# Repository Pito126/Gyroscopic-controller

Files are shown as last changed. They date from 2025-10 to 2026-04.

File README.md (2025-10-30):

# Gyroscopic Controller

Gyroskopický ovladač postavený na mikrokontroléru **ESP32**. Tento projekt umožňuje snadné ovládání zařízení (např. her, robotů nebo dronů) pomocí pohybu ruky nebo zařízení díky vestavěnému gyroskopu a akcelerometru.

## Funkce
- **Detekce pohybu**: Real-time čtení dat z gyroskopu pro detekci rotace a akcelerace.
- **Bezdrátové připojení**: Podpora Wi-Fi a Bluetooth přes ESP32 pro snadnou integraci s aplikacemi.
- **Snadná konfigurace**: Použití Arduino IDE nebo PlatformIO pro rychlý vývoj.
- **Open-source hardware**: Kompatibilní s běžnými senzory jako MPU6050 nebo LSM6DS3 (upravte podle vašeho setupu).

## Diagramy a schémata

### Schéma zapojení (PNG)
Zde je schéma zapojení ESP32 s gyroskopickým senzorem MPU6050:

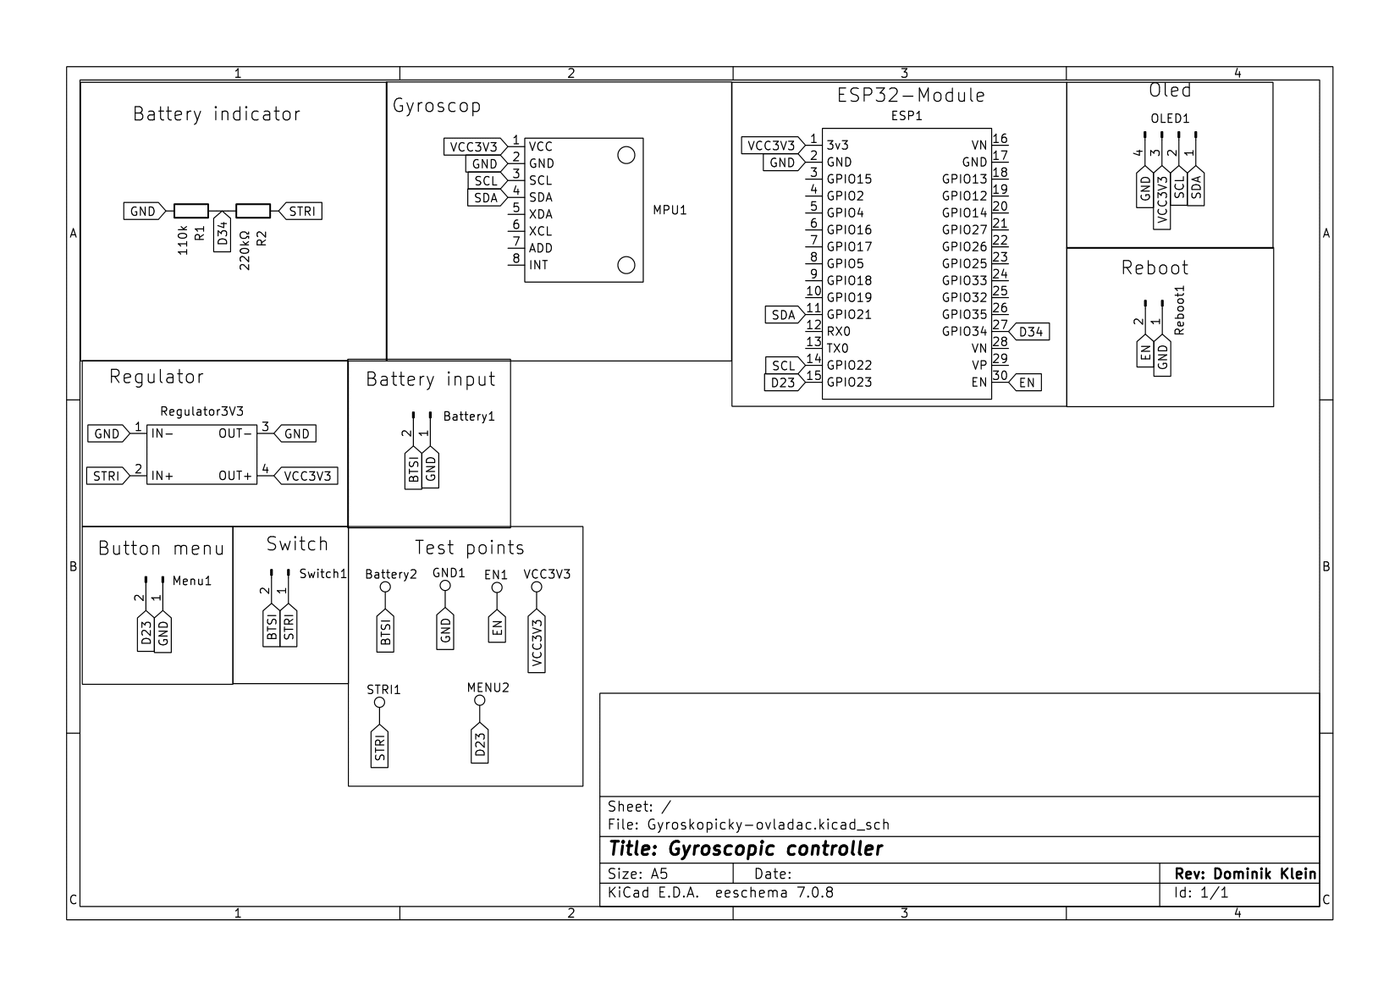
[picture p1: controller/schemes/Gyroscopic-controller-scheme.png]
Scheme


### Schéma PCB zapojení (PNG)
Zde je schéma PCB zapojení ESP32 s gyroskopickým senzorem MPU6050:

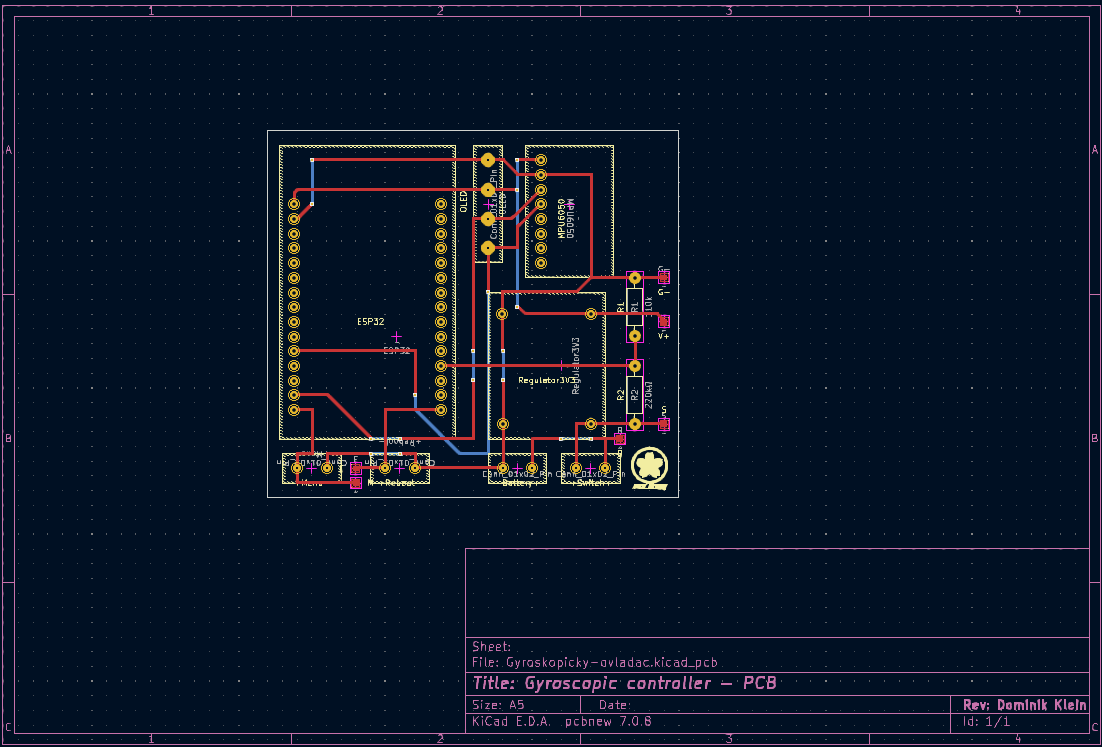
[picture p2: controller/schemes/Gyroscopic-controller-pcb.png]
Scheme-PCB)


## Požadavky
- **Hardware**:
  - ESP32 development board (např. ESP32-WROOM-32).
  - Gyroskopický senzor (např. MPU6050 připojený přes I2C).
  - Jumper wires a breadboard pro prototypování.
- **Software**:
  - Arduino IDE (verze 2.0+) s ESP32 board support.
  - Knihovny: `Wire` (pro I2C), `MPU6050` (pokud používáte tento senzor) – instalujte přes Library Manager.

## Instalace
1. Nainstalujte Arduino IDE z [oficiálního webu](https://www.arduino.cc/en/software).
2. Přidejte podporu pro ESP32: V IDE jděte do **File > Preferences**, přidejte URL `https://raw.githubusercontent.com/espressif/arduino-esp32/gh-pages/package_esp32_index.json` do Additional Board Manager URLs a nainstalujte "esp32" z Board Manager.
3. Stáhněte si tento repozitář: `git clone https://github.com/Pito126/Gyroscopic-controller.git`.
4. Otevřete soubory `.ino` v Arduino IDE.
5. Nahrajte kód na ESP32 přes USB.

## Použití
1. Připojte gyroskopický senzor k ESP32 (příklad pro MPU6050):
   - VCC → 3.3V
   - GND → GND
   - SCL → GPIO 22
   - SDA → GPIO 21
2. Nahrajte sketch (příklad v `src/main.ino` – upravte podle vašeho kódu).
3. Otevřete Serial Monitor (115200 baud) pro sledování dat pohybu.

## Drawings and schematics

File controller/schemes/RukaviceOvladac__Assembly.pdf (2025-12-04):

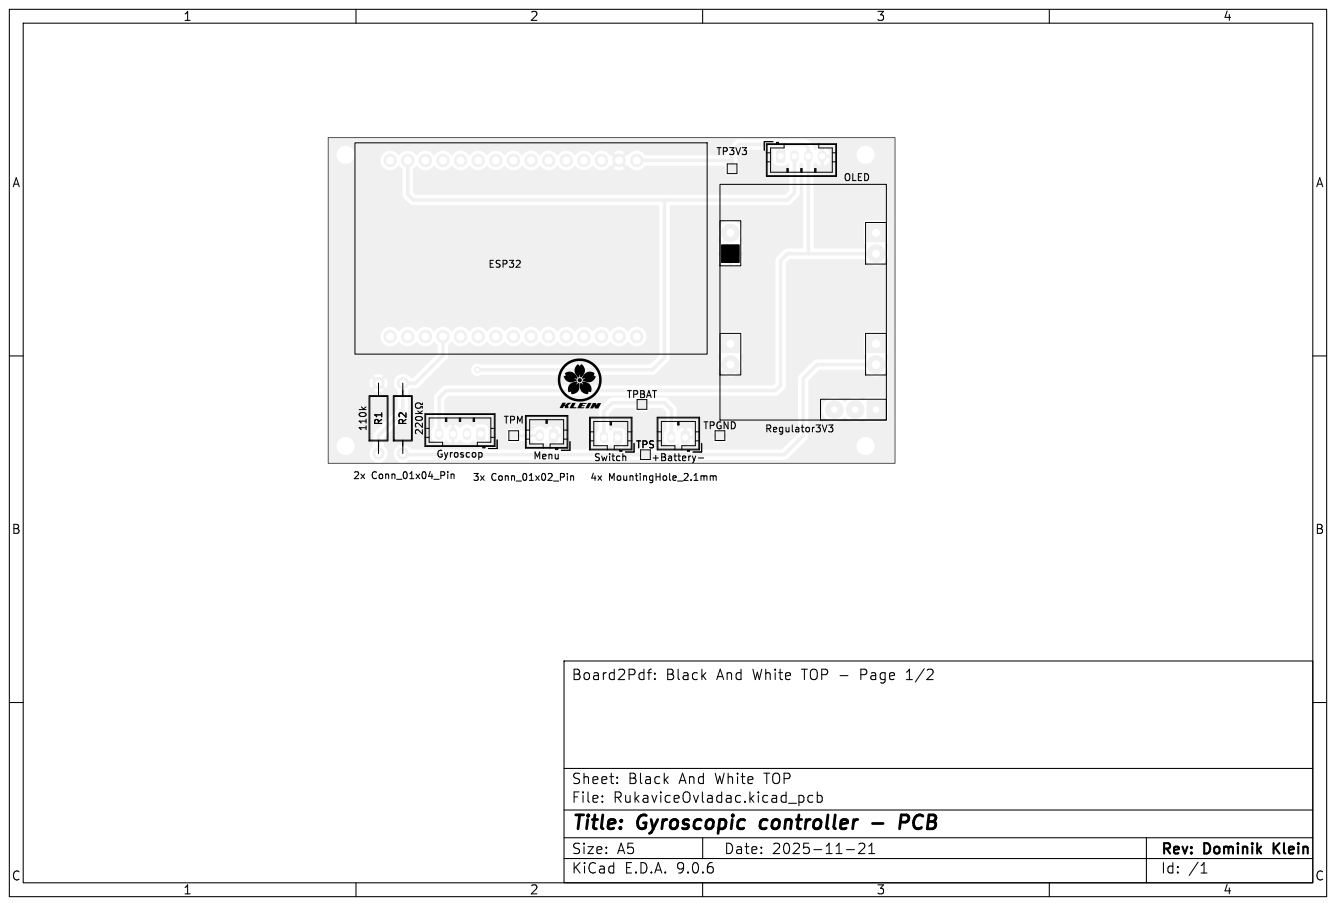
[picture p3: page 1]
+Battery-; OLED; TPS; Regulator3V3 TP3V3 TPBAT Switch ESP32; Menu; TPGND TPM; Gyroscop R¹; BC Date: 2025-11-21 KiCad; E.D.A. 9.0.6 Size: A5; Rev:; Dominik; Klein; File:; RukaviceOvladac.kicad_pcb Sheet:; Black; And; White; TOP; Board2Pdf:; And White; TOP -; Page; 4x MountingHole_2.1mm; 2x Conn_01x04_Pin; 3x Conn_01x02_Pin þÿ220k© R² 110k R¹

Id: /1 Title: Gyroscopic controller - PCB

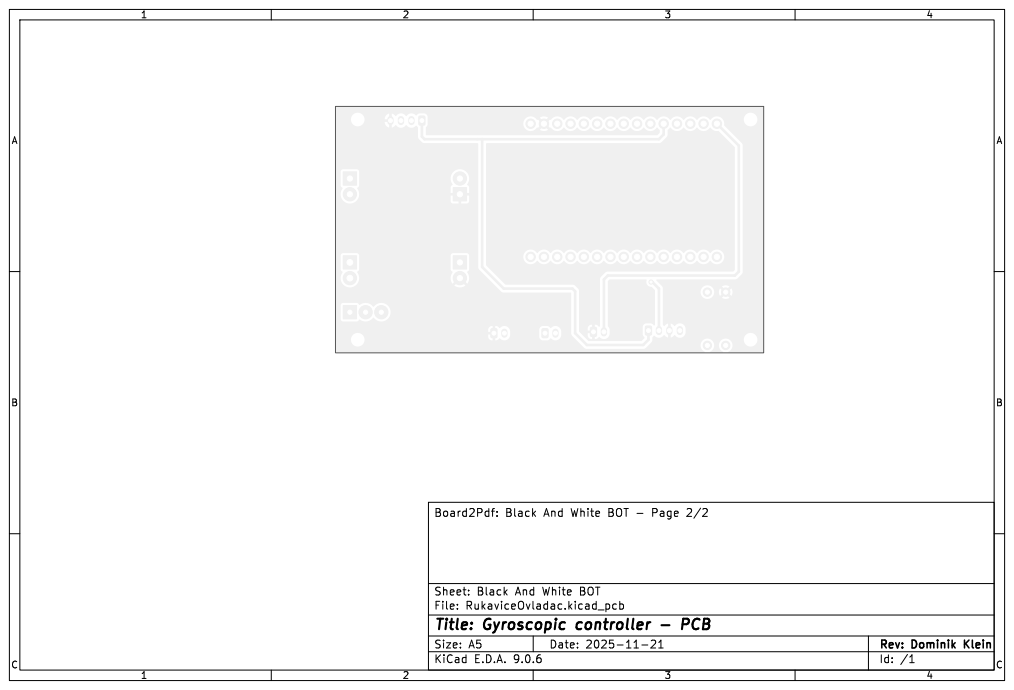
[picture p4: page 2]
BC Date: 2025-11-21 KiCad; E.D.A. 9.0.6 Size: A5; Rev:; Dominik; Klein; File:; RukaviceOvladac.kicad_pcb Sheet:; Black; And; White; BOT Board2Pdf:; And White; BOT -; Page 2/2

Id: /1 Title: Gyroscopic controller - PCB

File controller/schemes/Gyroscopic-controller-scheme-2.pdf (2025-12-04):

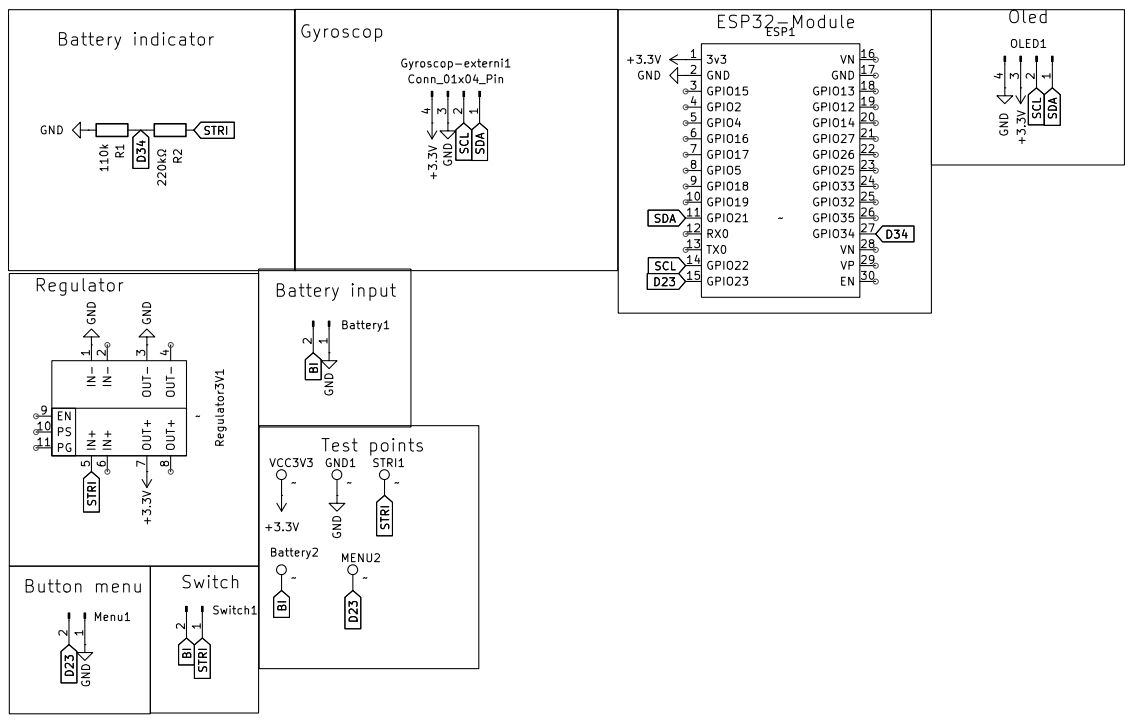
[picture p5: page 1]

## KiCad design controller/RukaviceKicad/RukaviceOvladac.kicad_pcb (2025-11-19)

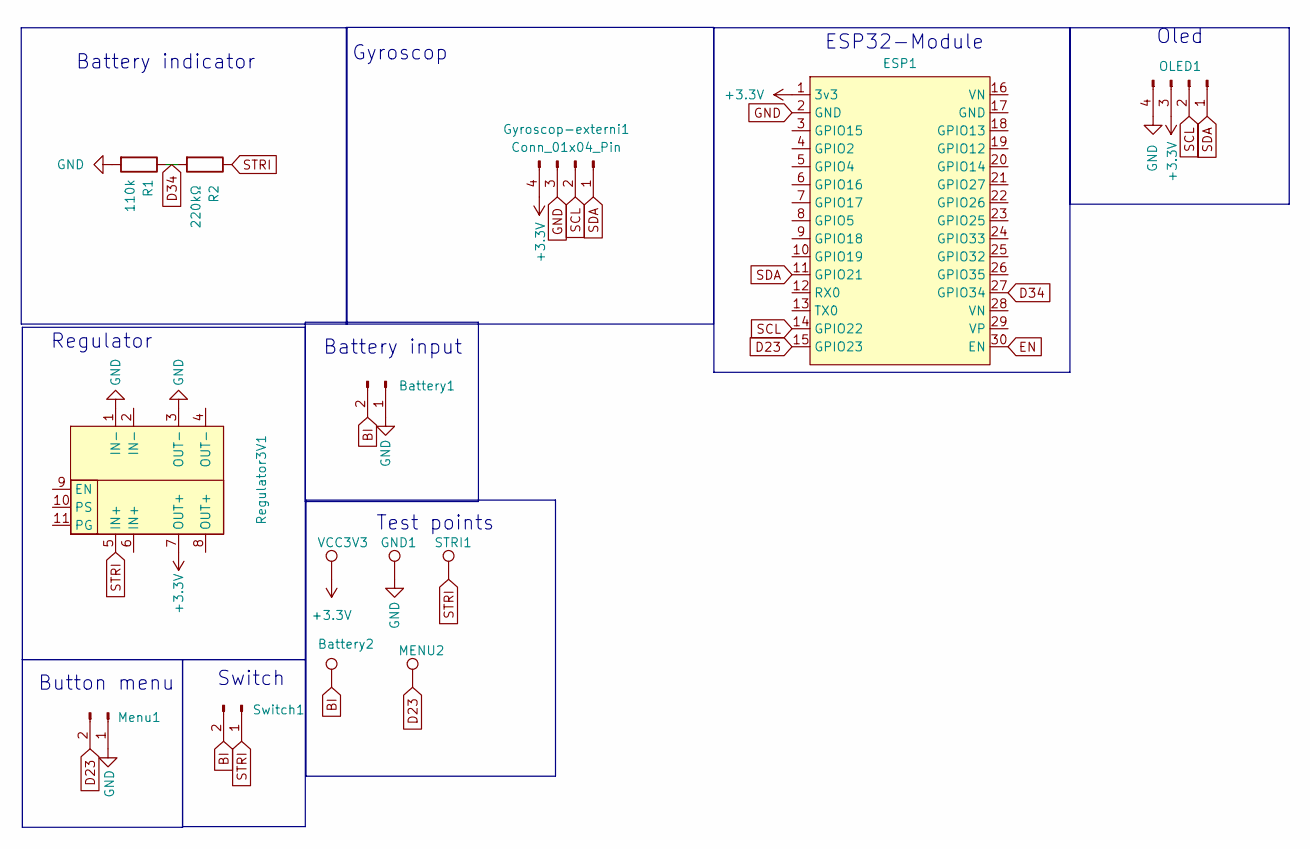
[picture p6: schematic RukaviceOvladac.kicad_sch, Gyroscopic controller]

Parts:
Battery1: Conn_01x02_Pin; JST_PH_B2B-PH-K_1x02_P2.00mm_Vertical
Battery2: TestPoint_Pad_1.0x1.0mm
ESP1: ESP32_30Pin_Module
GND1: TestPoint_Pad_1.0x1.0mm
Gyroscop-externi1: Conn_01x04_Pin; JST_PH_B4B-PH-K_1x04_P2.00mm_Vertical
MENU2: TestPoint_Pad_1.0x1.0mm
Menu1: Conn_01x02_Pin; JST_PH_B2B-PH-K_1x02_P2.00mm_Vertical
OLED1: Conn_01x04_Pin; JST_PH_B4B-PH-K_1x04_P2.00mm_Vertical
R1: 110k; R_Axial_DIN0207_L6.3mm_D2.5mm_P10.16mm_Horizontal
R2: 220kΩ; R_Axial_DIN0207_L6.3mm_D2.5mm_P10.16mm_Horizontal
Regulator3V1: Regulator3V3
STRI1: TestPoint_Pad_1.0x1.0mm
Switch1: Conn_01x02_Pin; JST_PH_B2B-PH-K_1x02_P2.00mm_Vertical
VCC3V3: TestPoint_Pad_1.0x1.0mm

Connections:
+3.3V: ESP1.1 (3v3), Gyroscop-externi1.4, OLED1.3, Regulator3V1.7 (OUT+), VCC3V3.1
BI: Battery1.2, Battery2.1, Switch1.2
D23: ESP1.15 (GPIO23), MENU2.1, Menu1.2
D34: ESP1.27 (GPIO34), R1.1, R2.2
EN: ESP1.30 (EN)
GND: Battery1.1, ESP1.2 (GND), GND1.1, Gyroscop-externi1.3, Menu1.1, OLED1.4, R1.2, Regulator3V1.1 (IN-), Regulator3V1.3 (OUT-)
SCL: ESP1.14 (GPIO22), Gyroscop-externi1.2, OLED1.2
SDA: ESP1.11 (GPIO21), Gyroscop-externi1.1, OLED1.1
STRI: R2.1, Regulator3V1.5 (IN+), STRI1.1, Switch1.1

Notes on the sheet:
Button menu
ESP32-Module
Gyroscop
Regulator
Oled
Battery indicator
Battery input
Switch
Test points

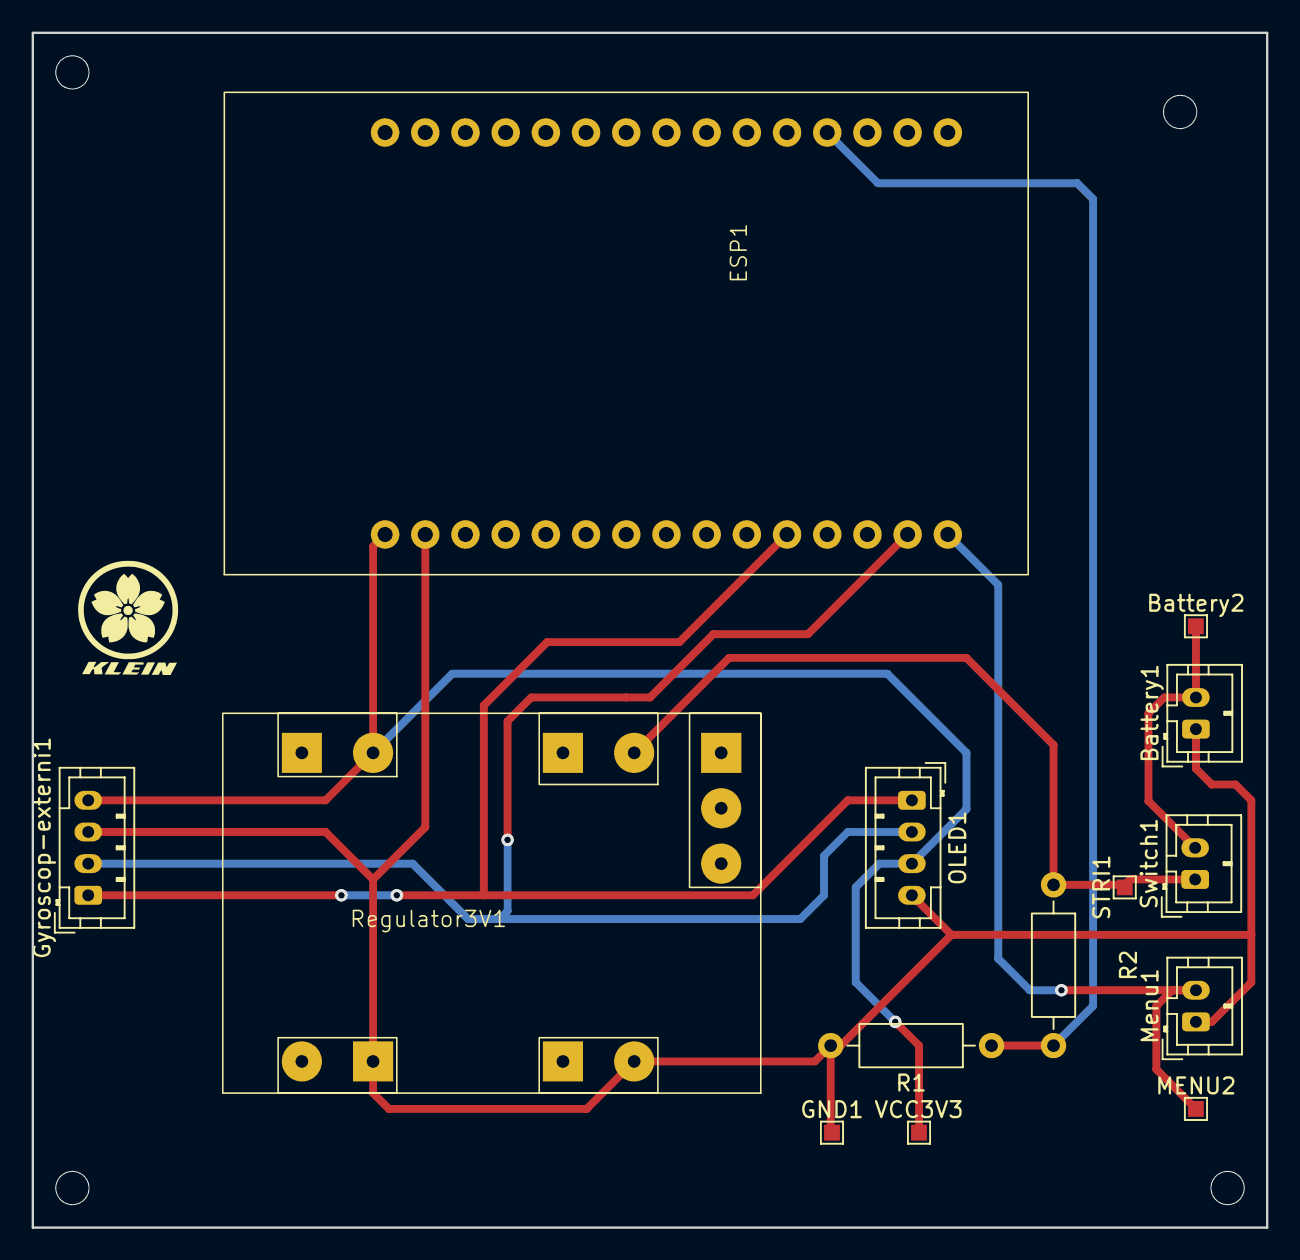
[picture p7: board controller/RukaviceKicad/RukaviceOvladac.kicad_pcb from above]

Board: 2 copper layers, 78.0 x 75.5 mm, 14 parts (0 on the bottom side), 8 nets.

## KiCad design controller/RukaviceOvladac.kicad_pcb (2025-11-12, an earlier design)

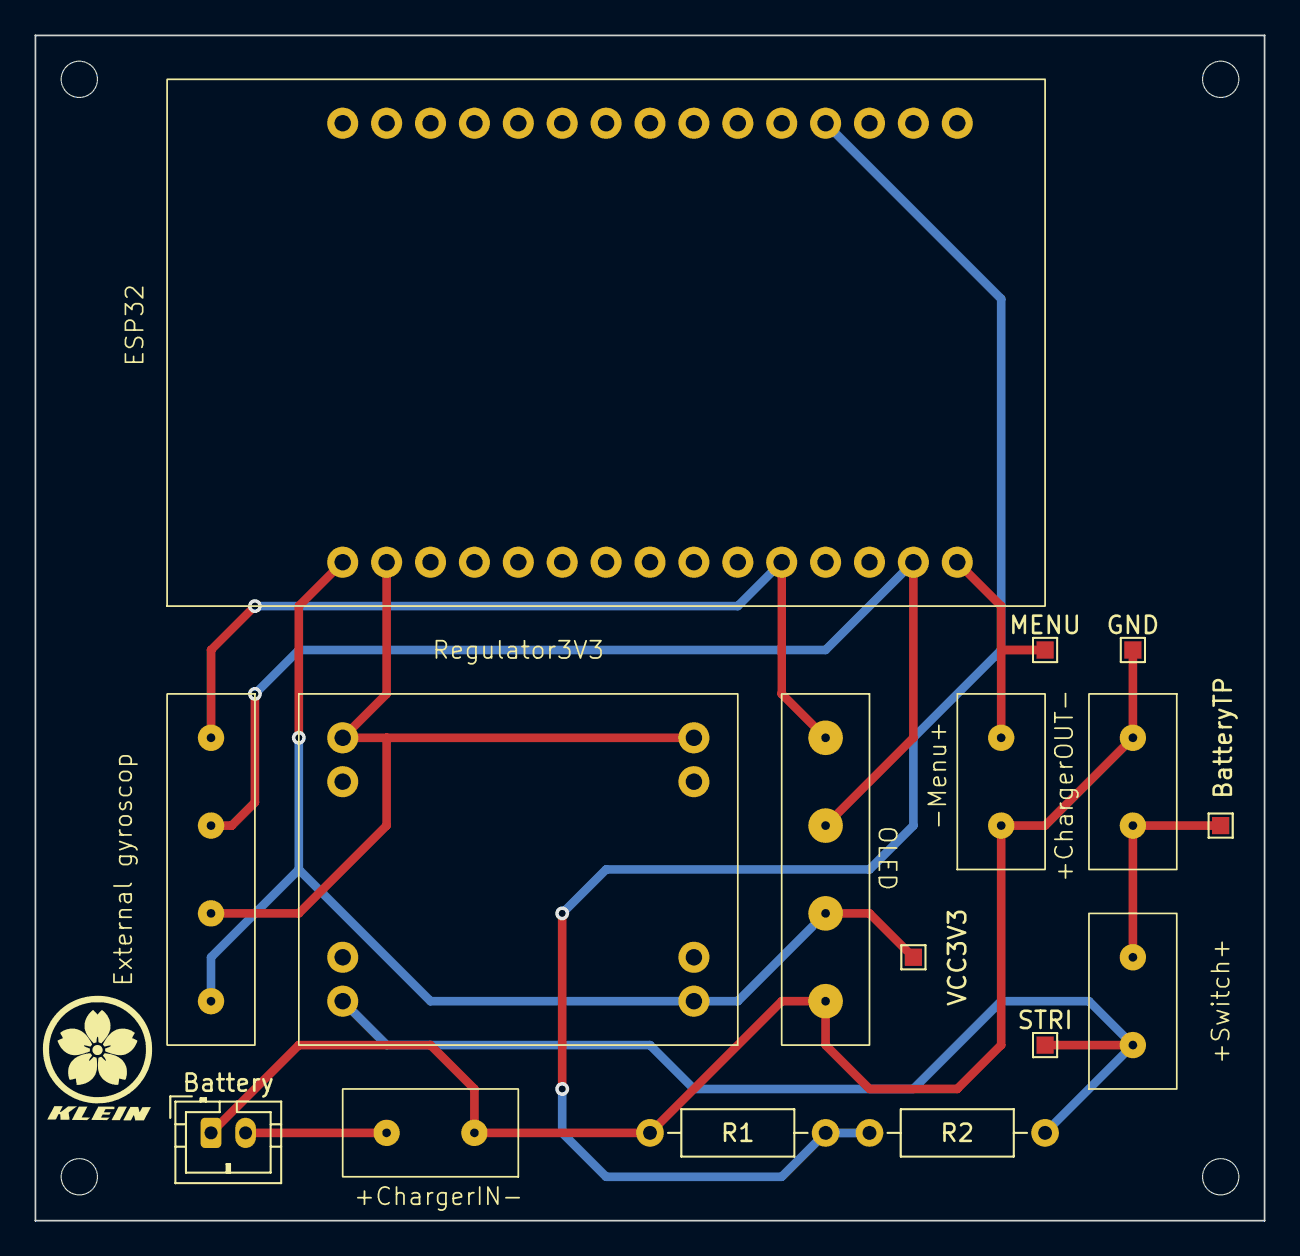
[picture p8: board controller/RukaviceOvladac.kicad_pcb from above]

Board: 2 copper layers, 71.1 x 68.6 mm, 16 parts (0 on the bottom side), 9 nets.

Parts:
+ChargerIN-: Conn_01x02_Pin; Tlacitko
+ChargerOUT-: Conn_01x02_Pin; Tlacitko
+Switch+: Conn_01x02_Pin; Tlacitko
-Menu+: Conn_01x02_Pin; Tlacitko
Battery: Conn_01x02_Pin; JST_PH_B2B-PH-K_1x02_P2.00mm_Vertical
BatteryTP: TestPoint_Pad_1.0x1.0mm
ESP32: ESP32_30Pin_Module
External gyroscop: Conn_01x04_Pin; Gyroskop-externi
GND: TestPoint_Pad_1.0x1.0mm
MENU: TestPoint_Pad_1.0x1.0mm
OLED: Conn_01x04_Pin; OLED
R1: 110k; R_Axial_DIN0207_L6.3mm_D2.5mm_P10.16mm_Horizontal
R2: 220kΩ; R_Axial_DIN0207_L6.3mm_D2.5mm_P10.16mm_Horizontal
Regulator3V3: Regulator
STRI: TestPoint_Pad_1.0x1.0mm
VCC3V3: TestPoint_Pad_1.0x1.0mm

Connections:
CHI+: +ChargerIN-.2, Battery.2
CHO+: +ChargerOUT-.2, +Switch+.2, BatteryTP.1
D23: -Menu+.2, ESP32.15 (GPIO23), MENU.1
D34: ESP32.27 (GPIO34), R1.1, R2.2
GND: +ChargerIN-.1, +ChargerOUT-.1, -Menu+.1, Battery.1, ESP32.2 (GND), External gyroscop.3, GND.1, OLED.4, R1.2, Regulator3V3.1 (IN-), Regulator3V3.5 (OUT-)
SCL: ESP32.14 (GPIO22), External gyroscop.2, OLED.2
SDA: ESP32.11 (GPIO21), External gyroscop.1, OLED.1
STRI: +Switch+.1, R2.1, Regulator3V3.4 (IN+), STRI.1
VCC3V3: ESP32.1 (3v3), External gyroscop.4, OLED.3, Regulator3V3.8 (OUT+), VCC3V3.1

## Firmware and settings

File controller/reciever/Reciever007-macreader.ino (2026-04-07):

#include <esp_now.h>
#include <WiFi.h>
#include <esp_wifi.h>

// --- Funkce pro čtení MAC adresy ---
void readMacAddress(){
  uint8_t baseMac[6];
  esp_err_t ret = esp_wifi_get_mac(WIFI_IF_STA, baseMac);
  if (ret == ESP_OK) {
    Serial.printf("%02x:%02x:%02x:%02x:%02x:%02x\n",
                  baseMac[0], baseMac[1], baseMac[2],
                  baseMac[3], baseMac[4], baseMac[5]);
  } else {
    Serial.println("Nepodarilo se nacist MAC adresu");
  }
}

// --- Struktura zprávy ---
typedef struct struct_message {
  char state[3];
  float pitch;
  float roll;
} struct_message;

struct_message myMessage;

// --- TB6612 piny ---
#define AIN1 17
#define AIN2 16
#define BIN1 18
#define BIN2 19
#define STBY 21
#define PWM_A 4
#define PWM_B 5

// --- Směr zapojení motorů ---
#define REVERSE_A false
#define REVERSE_B true

// --- Proměnné ---
unsigned long lastRecv = 0;
const unsigned long TIMEOUT_MS = 1000;
int speedLevels[4] = {100, 150, 200, 255};

// --- Funkce pro řízení motorů ---
void stopMotors() {
  digitalWrite(AIN1, LOW);
  digitalWrite(AIN2, LOW);
  digitalWrite(BIN1, LOW);
  digitalWrite(BIN2, LOW);
  analogWrite(PWM_A, 0);
  analogWrite(PWM_B, 0);
}

void setMotorA(bool forward, int pwm) {
  if (REVERSE_A) forward = !forward;
  digitalWrite(AIN1, forward ? HIGH : LOW);
  digitalWrite(AIN2, forward ? LOW : HIGH);
  analogWrite(PWM_A, pwm);
}

void setMotorB(bool forward, int pwm) {
  if (REVERSE_B) forward = !forward;
  digitalWrite(BIN1, forward ? HIGH : LOW);
  digitalWrite(BIN2, forward ? LOW : HIGH);
  analogWrite(PWM_B, pwm);
}

// --- Pohybové funkce ---
void forward(int lvl) {
  int pwm = speedLevels[lvl];
  setMotorA(true, pwm);
  setMotorB(true, pwm);
}

void backward(int lvl) {
  int pwm = speedLevels[lvl];
  setMotorA(false, pwm);
  setMotorB(false, pwm);
}

void left(int lvl) {
  int pwm = speedLevels[lvl];
  setMotorA(false, pwm);
  setMotorB(true, pwm);
}

void right(int lvl) {
  int pwm = speedLevels[lvl];
  setMotorA(true, pwm);
  setMotorB(false, pwm);
}

// --- ESP-NOW callback ---
void OnDataRecv(const esp_now_recv_info_t *info, const uint8_t *incomingData, int len) {
  memcpy(&myMessage, incomingData, sizeof(myMessage));
  lastRecv = millis();

  Serial.print("Pitch: "); Serial.print(myMessage.pitch, 1);
  Serial.print("  Roll: "); Serial.print(myMessage.roll, 1);
  Serial.print("  Stav: "); Serial.println(myMessage.state);

  char dir = myMessage.state[0];
  int level = myMessage.state[1] - '1';

  if (level < 0 || level > 3) {
    stopMotors();
    return;
  }

  switch (dir) {
    case 'F': forward(level); break;
    case 'B': backward(level); break;
    case 'L': left(level); break;
    case 'R': right(level); break;
    default: stopMotors(); break;
  }
}

// --- Nastavení ---
void setup() {
  Serial.begin(115200);

  WiFi.mode(WIFI_STA);
  WiFi.STA.begin();

  Serial.print("[DEFAULT] ESP32 Board MAC Address: ");
  readMacAddress();

  pinMode(AIN1, OUTPUT);
  pinMode(AIN2, OUTPUT);
  pinMode(BIN1, OUTPUT);
  pinMode(BIN2, OUTPUT);
  pinMode(STBY, OUTPUT);
  pinMode(PWM_A, OUTPUT);
  pinMode(PWM_B, OUTPUT);

  digitalWrite(STBY, HIGH);
  stopMotors();

  if (esp_now_init() != ESP_OK) {
    Serial.println("Chyba inicializace ESP-NOW!");
    while (1);
  }

  esp_now_register_recv_cb(OnDataRecv);

  Serial.println("Receiver pripraven");
}

// --- Hlavní smyčka ---
void loop() {
  if (millis() - lastRecv > TIMEOUT_MS) {
    stopMotors();
  }
}

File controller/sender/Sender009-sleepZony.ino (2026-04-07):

#include <Wire.h>            // Komunikace I2C pro OLED a gyroskop
#include <MPU6050.h>         // Gyroskop
#include <esp_now.h>         // WI-FI pro esp 32
#include <WiFi.h>            // Zapnutí WI-FI modů
#include <Adafruit_GFX.h>    // Funkce OLED displeje
#include <Adafruit_SH110X.h> // Nastavení displeje
#include <math.h>            // Matematické funkce
#include <esp_sleep.h>       // Light sleep

// --- OLED nastavení ---
#define SCREEN_WIDTH  128
#define SCREEN_HEIGHT 64

#define OLED_RESET    -1
#define BUTTON_PIN    23     // Light sleep funguje na libovolném GPIO
#define LONG_PRESS_MS 5000   // Doba držení pro uspání (ms)

Adafruit_SH1106G display(SCREEN_WIDTH, SCREEN_HEIGHT, &Wire, OLED_RESET);

// --- MPU6050 ---
MPU6050 mpu;

// --- Struktura zprávy pro ESP-NOW ---
// Definice struktury stejná jako na příjimači
typedef struct struct_message {
  char state[3]; // Řetěazec stavu, např. "F1", "R4", "I"
} struct_message;

struct_message myMessage; // Strukturovaná zpráva připravená k odesílání

// --- MAC adresa přijímače ---
uint8_t receiverAddress[] = {0xC0, 0x5D, 0x89, 0xCE, 0x33, 0x8C};

// --- Proměnné gyroskopu ---
float pitchFiltered = 0;
float rollFiltered  = 0;
unsigned long lastSend = 0;
const unsigned long SEND_INTERVAL = 300; // ms
char lastState[3] = "X";

// --- Baterie ovladače ---
const int   BAT_PIN     = 34;
const float R1          = 100000.0;
const float R2          = 220000.0; 
const float ADC_REF     = 3.3; // Referenční napětí převodníku
const int   ADC_RES     = 4095; // Rozlišení ADC
const float BAT_MAX     = 4.2; // Maximální napětí baterie
const float BAT_MIN     = 3.0; // Minimální napětí baterie
float batteryVoltage    = 0.0; // Napětí baterie
int   batteryPercent    = 0; // Procenta baterie
unsigned long lastBatteryUpdate = 0;
const unsigned long BATTERY_UPDATE_INTERVAL = 10000;

// --- OLED stránky ---
int  currentScreen     = 0;
bool lastButtonReading = HIGH;

void reinitMPU();


// Funkce pro uspání ESP32 spotřeba 0.8 místo 107 mA
void goToSleep() {
  Serial.println("Uspavam do light sleep...");

  // Zpráva na displeji
  display.clearDisplay();
  display.setTextSize(1);
  display.setTextColor(SH110X_WHITE);
  display.drawRect(0, 0, SCREEN_WIDTH, SCREEN_HEIGHT, SH110X_WHITE);
  display.setCursor(20, 20);
  display.println("  Uspavam...");
  display.setCursor(4, 36);
  display.println("Stiskni pro buzeni");
  display.fillCircle(48, 52, 2, SH110X_WHITE);
  display.fillCircle(62, 52, 2, SH110X_WHITE);
  display.fillCircle(76, 52, 2, SH110X_WHITE);
  display.display();
  delay(1000);

  // Vypni OLED
  display.clearDisplay();
  display.display();

  // Ukonči ESP-NOW a WiFi
  esp_now_deinit();
  WiFi.disconnect(true);
  WiFi.mode(WIFI_OFF);

  // Probuzení přes GPIO 23 (LOW = stisk při INPUT_PULLUP)
  gpio_wakeup_enable((gpio_num_t)BUTTON_PIN, GPIO_INTR_LOW_LEVEL);
  esp_sleep_enable_gpio_wakeup();

  Serial.println("Jdu spat...");
  delay(100);
  esp_light_sleep_start();

  // --- Po probuzení pokračuje kód zde ---
  Serial.println("Probuzen z light sleep");

  // Počkej na puštění tlačítka
  while (digitalRead(BUTTON_PIN) == LOW) delay(10);
  delay(50);

  // Znovu inicializuj WiFi a ESP-NOW
  WiFi.mode(WIFI_STA);
  if (esp_now_init() != ESP_OK) {
    Serial.println("Chyba ESP-NOW reinit!");
  } else {
    esp_now_peer_info_t peerInfo = {};
    memcpy(peerInfo.peer_addr, receiverAddress, 6);
    peerInfo.channel = 0;
    peerInfo.encrypt = false;
    esp_now_add_peer(&peerInfo);
    Serial.println("ESP-NOW reinicializovan");
  }

  // Znovu inicializuj MPU
  reinitMPU();

  // Zapni OLED
  display.begin(0x3C, true);
  display.clearDisplay();
  display.display();

  Serial.println("Plny provoz obnoven");
}

// Stiknutí tlačítka přepne další obrazovku, delší podržení hodí tlačítko do sleepu
void handleButton() {
  static unsigned long pressStart = 0;
  static bool longPressFired      = false;

  bool reading = digitalRead(BUTTON_PIN);

  // Tlačítko právě stisknuto
  if (reading == LOW && lastButtonReading == HIGH) {
    pressStart     = millis();
    longPressFired = false;
  }

  // Kontrola long pressu
  if (reading == LOW && !longPressFired) {
    if (millis() - pressStart >= LONG_PRESS_MS) {
      longPressFired = true;
      goToSleep();
    }
  }

  // Krátký stisk = přepni obrazovku
  if (reading == HIGH && lastButtonReading == LOW && !longPressFired) {
    currentScreen++;
    if (currentScreen > 2) currentScreen = 0;
    Serial.print("Prepinám na stranku: ");
    Serial.println(currentScreen);
    delay(250);
  }

  lastButtonReading = reading;
}

// --- Funkce: reinicializace MPU ---
void reinitMPU() {
  Serial.println("Reinicializuji MPU...");
  mpu.initialize();
  delay(200);
}

// --- Funkce: měření baterie ---
void updateBattery() {
  const int SAMPLES = 10;

  analogSetPinAttenuation(BAT_PIN, ADC_11db);

  long sum = 0;
  for (int i = 0; i < SAMPLES; i++) {
    sum += analogRead(BAT_PIN);
    delay(5);
  }
  float avgADC = sum / (float)SAMPLES;

  // 3.78 / 1.310 = 2.885
  batteryVoltage = (avgADC / 4095.0f) * 3.9f * 2.885f;

  if      (batteryVoltage >= BAT_MAX) batteryPercent = 100;
  else if (batteryVoltage <= BAT_MIN) batteryPercent = 0;
  else batteryPercent = (int)((batteryVoltage - BAT_MIN) * (100.0f / (BAT_MAX - BAT_MIN)));
}
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
